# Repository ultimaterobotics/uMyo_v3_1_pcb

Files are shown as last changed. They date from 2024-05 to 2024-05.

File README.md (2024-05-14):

# uMyo_v3_1_pcb
PCB files for uMyo v3.1

This is a KiCAD 6 project for the latest (as of upload date) version of uMyo boards.

PCB is licensed under CERN-OHL-P-2.0 - we use MIT license for our software/firmware projects, but it seems that for hardware it doesn't work well, so we applied this option. In our understanding, it should permit anyone to use this design as a whole or incorporate its parts into other projects with no restrictions (including commercial use), except for claiming that it was not derived from our project. If you want to use it but something in this license prevents you from doing that - please contact us, we'll see what can be done about it.

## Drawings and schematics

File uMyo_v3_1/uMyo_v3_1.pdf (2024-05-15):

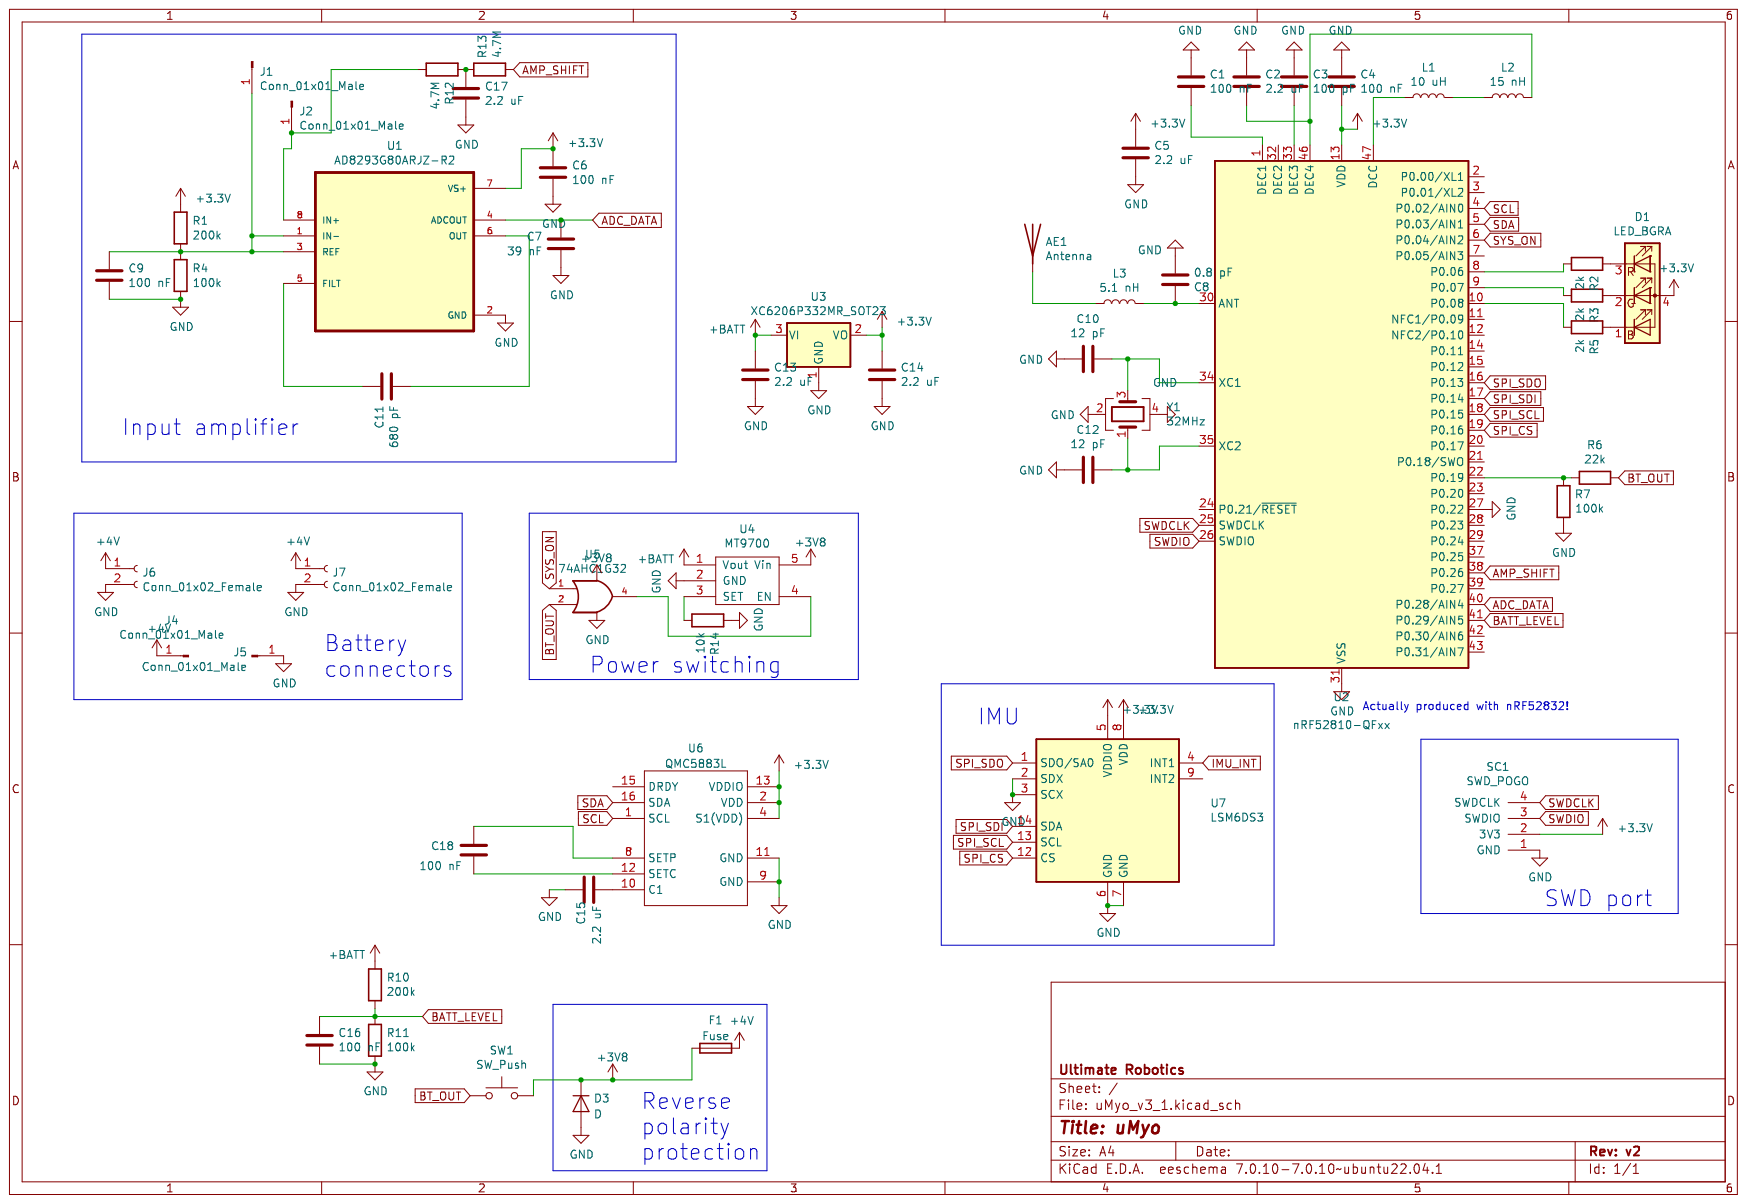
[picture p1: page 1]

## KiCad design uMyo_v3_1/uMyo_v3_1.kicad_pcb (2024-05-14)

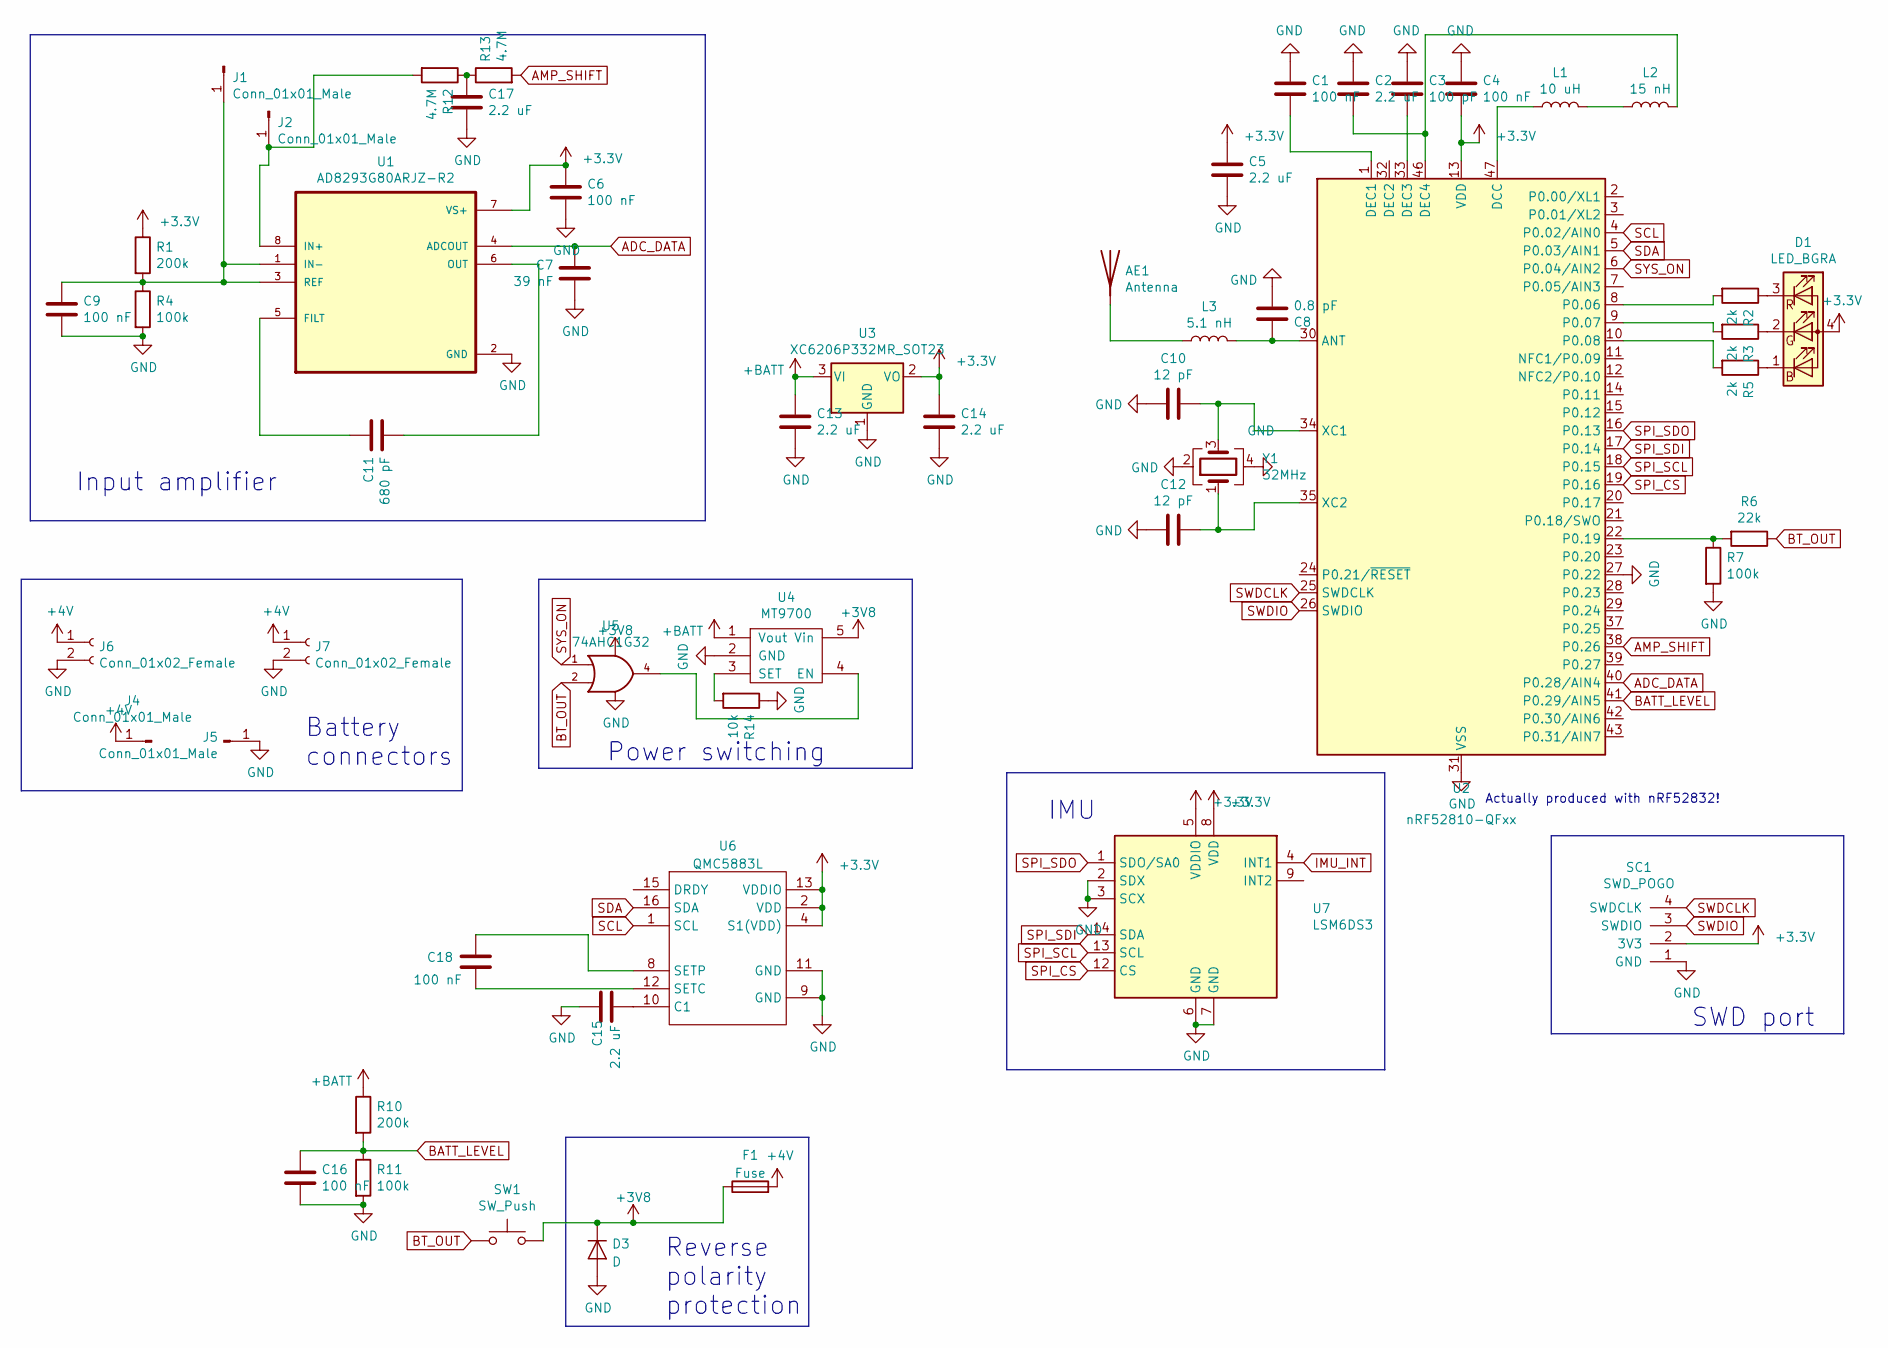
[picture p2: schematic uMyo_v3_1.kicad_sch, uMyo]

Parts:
AE1: Antenna; KH3216-A55; JLCPN C484541
C1, C4, C6, C9, C16, C18: 100 nF; C_0402_1005Metric; JLCPN C1525
C2, C5, C13, C14, C15, C17: 2.2 uF; C_0402_1005Metric; JLCPN C12530
C3: 100 pF; C_0402_1005Metric; JLCPN C1546
C7: 39 nF; C_0402_1005Metric; JLCPN C117753
C8: 0.8 pF; C_0402_1005Metric; JLCPN C88902
C10, C12: 12 pF; C_0402_1005Metric; JLCPN C1547
C11: 680 pF; C_0402_1005Metric; JLCPN C113781
D1: LED_BGRA; LED_RGB_0603_a4; JLCPN C282128
D3: D; D_SOD-323; JLCPN C191023
F1: Fuse; Fuse_0603_1608Metric; JLCPN C207011
J1, J2: Conn_01x01_Male; uMyo_dry_connector
J4, J5: Conn_01x01_Male; conn_16_20
J6, J7: Conn_01x02_Female; JST_PH_S2B-PH-SM4-TB_1x02-1MP_P2.00mm_Horizontal; JLCPN C520130
L1: 10 uH; L_0603_1608Metric; JLCPN C1035
L2: 15 nH; L_0402_1005Metric; JLCPN C27143
L3: 5.1 nH; L_0402_1005Metric; JLCPN C86066
R1, R10: 200k; R_0402_1005Metric; JLCPN C25764
R2, R3, R5: 2k; R_0402_1005Metric; JLCPN C4109
R4, R7, R11: 100k; R_0402_1005Metric; JLCPN C25741
R6: 22k; R_0402_1005Metric; JLCPN C25768
R12, R13: 4.7M; R_0402_1005Metric; JLCPN C227116
R14: 10k; R_0402_1005Metric; JLCPN C25744
SC1: SWD_POGO
SW1: SW_Push; SW_SPST_CK_RS282G05A3; JLCPN C2845294
U1: AD8293G80ARJZ-R2; SOT-23-8; JLCPN C141950
U2: nRF52810-QFxx; QFN-48-1EP_6x6mm_Pitch0.4mm; JLCPN C141828
U3: XC6206P332MR_SOT23; SOT-23; JLCPN C5446
U4: MT9700; SOT-23-5; JLCPN C89855
U5: 74AHC1G32; SOT-23-5; JLCPN C507209
U6: QMC5883L; LGA-16_3x3mm_P0.5mm; JLCPN C976032
U7: LSM6DS3; LGA-14_3x2.5mm_P0.5mm_LayoutBorder3x4y; JLCPN C967633
Y1: 32MHz; Crystal_SMD_2016-4Pin_2.0x1.6mm; JLCPN C843260

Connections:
+3V3: C4.1, C5.2, C6.2, C14.2, D1.4 (A), R1.1, SC1.2 (3V3), U1.7 (VS+), U2.13 (VDD), U2.36 (VDD), U2.48 (VDD), U3.2 (VO), U6.2 (VDD), U6.4 (S1(VDD)), U6.13 (VDDIO), U7.5 (VDDIO), U7.8 (VDD)
+3V8: D3.1 (K), F1.1, SW1.2, U4.5 (Vin), U5.5 (VCC)
+4V: F1.2, J4.1, J6.1, J7.1
+BATT: C13.2, R10.1, U3.3 (VI), U4.1 (Vout)
ADC_DATA: C7.1, U1.4 (ADCOUT), U2.40 (P0.28/AIN4)
AMP_SHIFT: R13.2, U2.38 (P0.26)
BATT_LEVEL: C16.2, R10.2, R11.1, U2.41 (P0.29/AIN5)
BT_OUT: R6.1, SW1.1, U5.2
GND: C1.2, C2.2, C3.2, C4.2, C5.1, C6.1, C7.2, C8.2, C9.1, C10.1, C12.1, C13.1, C14.1, C15.2, C16.1, C17.1, D3.2 (A), J5.1, J6.2, J7.2, R4.2, R7.2, R11.2, R14.1, SC1.1 (GND), U1.2 (GND), U2.27 (P0.22), U2.31 (VSS), U2.45 (VSS), U2.49 (VSS), U3.1 (GND), U4.2 (GND), U5.3 (GND), U6.9 (GND), U6.11 (GND), U7.2 (SDX), U7.3 (SCX), U7.6 (GND), U7.7 (GND), Y1.2, Y1.4
IMU_INT: U7.4 (INT1)
unnamed: AE1.1 (A), L3.1
unnamed: C1.1, U2.1 (DEC1)
unnamed: C2.1, L2.2, U2.46 (DEC4)
unnamed: C3.1, U2.33 (DEC3)
unnamed: C8.1, L3.2, U2.30 (ANT)
unnamed: C9.2, J1.1, R1.2, R4.1, U1.1 (IN-), U1.3 (REF)
unnamed: C10.2, U2.34 (XC1), Y1.3
unnamed: C11.1, U1.5 (FILT)
unnamed: C11.2, U1.6 (OUT)
unnamed: C12.2, U2.35 (XC2), Y1.1
unnamed: C15.1, U6.10 (C1)
unnamed: C17.2, R12.1, R13.1
unnamed: C18.1, U6.12 (SETC)
unnamed: C18.2, U6.8 (SETP)
unnamed: D1.1 (BK), R5.1
unnamed: D1.2 (GK), R3.1
unnamed: D1.3 (RK), R2.1
unnamed: J2.1, R12.2, U1.8 (IN+)
unnamed: L1.1, U2.47 (DCC)
unnamed: L1.2, L2.1
unnamed: R2.2, U2.8 (P0.06)
unnamed: R3.2, U2.9 (P0.07)
unnamed: R5.2, U2.10 (P0.08)
unnamed: R6.2, R7.1, U2.22 (P0.19)
unnamed: R14.2, U4.3 (SET)
unnamed: U4.4 (EN), U5.4
SCL: U2.4 (P0.02/AIN0), U6.1 (SCL)
SDA: U2.5 (P0.03/AIN1), U6.16 (SDA)
SPI_CS: U2.19 (P0.16), U7.12 (CS)
SPI_SCL: U2.18 (P0.15), U7.13 (SCL)
SPI_SDI: U2.17 (P0.14), U7.14 (SDA)
SPI_SDO: U2.16 (P0.13), U7.1 (SDO/SA0)
SWDCLK: SC1.4 (SWDCLK), U2.25 (SWDCLK)
SWDIO: SC1.3 (SWDIO), U2.26 (SWDIO)
SYS_ON: U2.6 (P0.04/AIN2), U5.1

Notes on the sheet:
SWD port
Power switching
Battery connectors
IMU
Reverse polarity protection
Actually produced with nRF52832!
Input amplifier

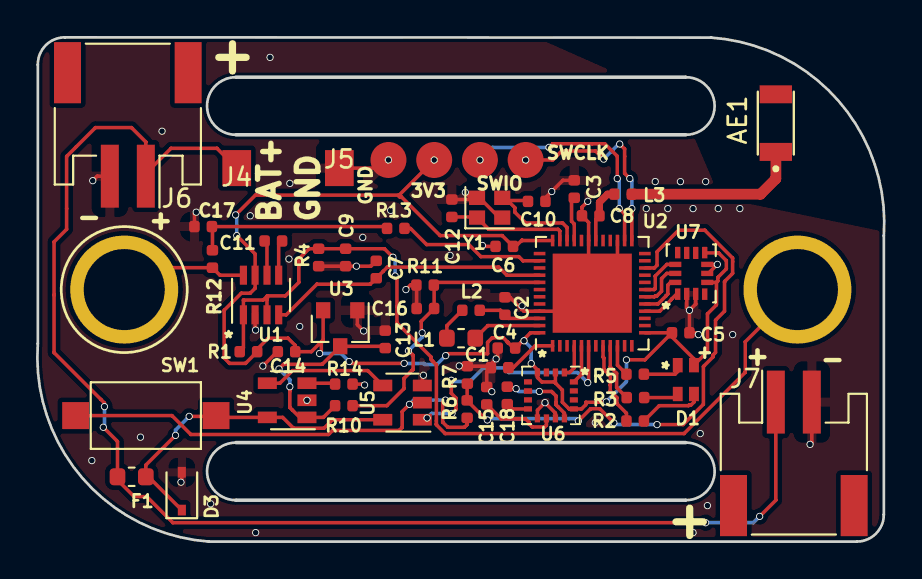
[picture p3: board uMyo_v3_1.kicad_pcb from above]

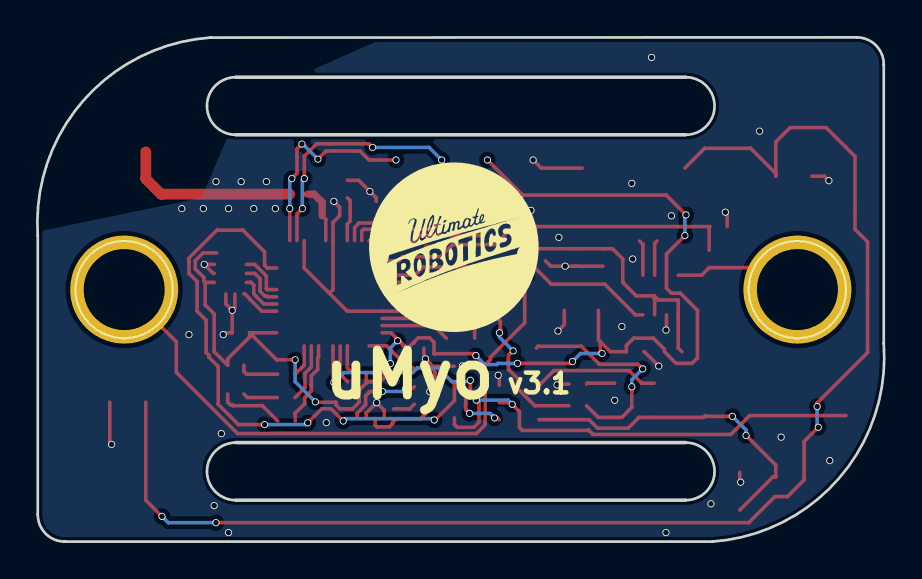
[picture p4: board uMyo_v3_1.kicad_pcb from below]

Board: 2 copper layers, 47.1 x 28.0 mm, 53 parts (2 on the bottom side), 44 nets.

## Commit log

2024-05-14 Added KiCAD PCB files
    Initial upload of all KiCAD files for uMyo v3_1
    [uMyo_v3_1.kicad_pcb, uMyo_v3_1.kicad_sch, uMyo_v3_1.sch]
2024-05-15 Uploaded v3.1 schematics in PDF
    The old file in the folder was from v2, replaced with correct one
